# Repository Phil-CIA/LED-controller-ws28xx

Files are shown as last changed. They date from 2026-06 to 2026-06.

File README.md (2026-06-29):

# My LED Controller

Standalone ESP32 + WS281x project.

This repo now supports two firmware paths:
- custom firmware in `src/main.cpp` (serial-driven tests and demo)
- official WLED firmware (Wi-Fi + WLED app control)

This repo now also supports two hardware targets:
- `breadboard` target profile
- `pcb` target profile

Each target has independent identity lock (port/chip/MAC) in `scripts/flash-targets.json`.

## Hardware
- MCU: ESP32 family (default board config: esp32dev)
- LED data: GPIO18
- LED type: WS281x (NEO_GRB + 800kHz)
- LED count: 300
- Level shifter: 74H125
- Upload port: COM5

## Quick start
1. Set active target profile
   - Breadboard: `powershell -ExecutionPolicy Bypass -File scripts/set-active-target.ps1 -TargetName breadboard`
   - PCB: `powershell -ExecutionPolicy Bypass -File scripts/set-active-target.ps1 -TargetName pcb`
2. Build custom firmware for selected target
   - `powershell -ExecutionPolicy Bypass -File scripts/guarded-flash.ps1 -Action build`
3. Upload custom firmware for selected target (guarded)
   - `powershell -ExecutionPolicy Bypass -File scripts/guarded-flash.ps1 -Action upload`
4. Monitor
   - `platformio device monitor -b 115200 -p COM5`

## Target profile setup
Before first guarded flash on a target, pin its immutable MAC:
- `powershell -ExecutionPolicy Bypass -File scripts/set-target-mac.ps1 -TargetName pcb -ExpectedMac 11:22:33:44:55:66`

If `expectedMac` is empty for a target, guarded upload refuses to flash.

## WLED quick start (Wi-Fi + app)
1. Set active target profile first (`breadboard` or `pcb`).
2. Use the official installer at `https://install.wled.me` (ESP32 target).
3. Select the target COM port and complete flashing through the installer UI.
4. On first boot, connect to the WLED access point (`WLED-xxxxxx`) and open `http://4.3.2.1`.
5. In WLED settings, set hardware values to match this strip:
   - GPIO: `18`
   - LED count: `300`
   - Color order: `GRB`
6. Configure home Wi-Fi credentials in WLED settings and save.
7. Open the WLED app and add the device using `wled.local` or the assigned IP.
8. Set WLED max current to `12000 mA` for steady-state operation.
9. Discover by target profile:
   - Breadboard: `powershell -ExecutionPolicy Bypass -File scripts/discover-wled.ps1 -TargetName breadboard -OpenUi`
   - PCB: `powershell -ExecutionPolicy Bypass -File scripts/discover-wled.ps1 -TargetName pcb -OpenUi`

### If device reboots with `invalid header`
- This indicates an incompatible direct flash layout.
- Recover to known-good firmware with guarded upload:
  - `powershell -ExecutionPolicy Bypass -File scripts/guarded-flash.ps1 -Action upload`
- Then use `install.wled.me` instead of raw one-file `esptool write-flash` for WLED.

## Serial commands
- `on` => resume animation
- `off` => LEDs off
- `rainbow` => return to rainbow mode
- `white`, `red`, `green`, `blue` => solid color test
- `probe` => raw GPIO18 pulse test
- `b0` to `b255` => set brightness

## Rev B action list (from validated PCB bring-up)
- Keep LED outputs as validated:
   - external strip data on `GPIO18`
   - onboard 3-LED chain on `GPIO19`
- Keep sensor wiring as validated:
   - AHT20 `SDA=GPIO21`, `SCL=GPIO22`
   - I2C address detected at `0x38`
- Fix switch hardware biasing on PCB:
   - Current switch pins (`GPIO34`, `GPIO35`, `GPIO36`, `GPIO39`) have no internal pull-up/down support.
   - Add external pull resistors per switch (recommended: `10k` pull-up to `3.3V`, button to `GND`, active-low).
- Preserve guarded flash identity lock per target in `scripts/flash-targets.json`.
- Keep target-separated profiles (`breadboard`, `pcb`) and avoid MAC reuse across targets.

## PCB diagnostics commands
- `aht20` or `sensor` => read temperature/humidity from AHT20
- `i2cscan` or `scan` => scan bus and print detected I2C addresses
- `switches` or `inputs` => print raw switch pin states
- `boardcheck` or `diag` => run sensor + switches diagnostics together

## Notes
- If your exact ESP32 board is different, update `board` in platformio.ini.
- If colors are wrong, adjust pixel order in src/main.cpp.
- Keep strict target guardrails in place; do not flash unknown devices opportunistically.
- Use dedicated VS Code tasks per target (`Breadboard:*` and `PCB:*`).

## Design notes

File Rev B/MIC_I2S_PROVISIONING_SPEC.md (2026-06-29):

# Rev B Optional MIC_I2S Provisioning Spec

Date: 2026-06-29
Scope: Provision-only support for future WLED audio-reactive microphone input.

## Intent
- Add optional microphone connectivity in Rev B without requiring immediate microphone population.
- Keep primary LED controller behavior unchanged when microphone is not installed.
- Prefer I2S digital microphone compatibility for WLED.

## Locked Module and Connector
- Module lock: INMP441 I2S microphone module, 14 mm form factor.
- Implementation lock: custom device footprint already placed as U2.
- KiCad symbol/library: 1My_IC's:INMP441.
- KiCad footprint/library: 1My_Parts_ ICs:inmp441.
- Physical interface: dual 1x3 headers (2.54 mm), total 6 pins.

## Electrical Interface
Required nets for the optional interface:
- MIC_VDD
- MIC_GND
- MIC_I2S_BCLK
- MIC_I2S_WS
- MIC_I2S_SD
- MIC_LR_SEL

Current netlist implementation:
- U2 VDD is tied to +5V_CTRL.
- U2 L/R is tied to GND.

Optional protection/conditioning footprints (DNI by default):
- 3x series resistors (one per I2S signal, nominal 22R to 100R)
- 100 nF decoupling capacitor at MIC_3V3
- 10 uF local bulk capacitor at MIC_3V3

## Locked Pin Map (Classic ESP32)
Set A is now locked:
- GPIO32 -> MIC_I2S_BCLK
- GPIO33 -> MIC_I2S_WS
- GPIO35 -> MIC_I2S_SD
- MIC_LR_SEL -> GND (left-channel select for WLED compatibility)

## Locked Pin Functions (U2)
1. L/R -> MIC_LR_SEL (tied to GND)
2. WS -> MIC_I2S_WS
3. SCLK -> MIC_I2S_BCLK
4. SD -> MIC_I2S_SD
5. VDD -> MIC_VDD (currently +5V_CTRL)
6. GND -> MIC_GND

## KiCad Schematic Tasks
1. Keep U2 as the locked INMP441 device symbol and footprint pair.
2. Verify the U2 six pin functions match the locked mapping above.
3. Keep microphone path optional in documentation/BOM intent.
4. Keep design local to Rev B schematic only.

## KiCad PCB Tasks
1. Place/keep the U2 footprint in a low-noise region away from switching and high current LED paths.
2. Keep I2S traces short and direct; avoid crossing noisy return paths.
3. Add clear silkscreen orientation and signal labels.
4. Leave microphone and optional passives as DNI unless intentionally enabled.

## Verification
- ERC: no new unresolved errors caused by MIC_I2S nets.
- DRC: no new clearance/connectivity violations.
- Pin conflict check: selected I2S pins do not conflict with existing mapped functions.
- Pinout check: U2 pin-function mapping matches the locked U2 list.

## Future Bring-Up
When a microphone is populated:
1. Enable WLED AudioReactive.
2. Configure I2S mode.
3. Enter the final BCLK, WS, SD GPIO mapping.
4. Save config and perform a hardware reset.

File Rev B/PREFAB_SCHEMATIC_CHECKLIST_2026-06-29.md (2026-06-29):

# Rev B Schematic Pre-Fab Checklist

Date: 2026-06-29
Design: Rev B
Scope: Schematic-only pre-fab gate before PCB reroute.

## Baseline Inputs
- Schematic: [Rev B/My LED controller Rev B.kicad_sch](Rev B/My LED controller Rev B.kicad_sch)
- Netlist: [Rev B/My LED controller Rev B.net](Rev B/My LED controller Rev B.net)
- ERC report (new): [Rev B/ERC_PREFAB_2026-06-29.rpt](Rev B/ERC_PREFAB_2026-06-29.rpt)

## Gate Criteria
1. ERC errors: 0 required to pass.
2. ERC warnings: either resolved or explicitly accepted with rationale.
3. New microphone path fully documented and electrically intentional.
4. All power-net assumptions for microphone module confirmed.

## Current ERC Summary
- Total messages: 48
- Errors: 1
- Warnings: 47
- Source: [Rev B/ERC_PREFAB_2026-06-29.rpt](Rev B/ERC_PREFAB_2026-06-29.rpt)
- Latest synced run (after alias/severity tuning): 35 messages, 1 error, 34 warnings.
- Source: [Rev B/ERC_SYNC_NOW_2026-06-29.rpt](Rev B/ERC_SYNC_NOW_2026-06-29.rpt)

## Change Coverage Audit (2026-06-29)
Original mic-scope intent vs current schematic/netlist implementation.

Implemented:
- INMP441 symbol and footprint are present as U2.
- Set A I2S mapping is present:
  - GPIO32 -> MIC_I2S_BCLK
  - GPIO33 -> MIC_I2S_WS
  - GPIO35 -> MIC_I2S_SD
- L/R is tied to GND (left-channel select behavior).
- U2 VDD is tied to +5V_CTRL.

Open/mismatch items:
- GPIO33 still reports ERC pin_not_driven and is not closed yet.
- Net naming mismatch from earlier plan: MIC_VDD/MIC_GND/MIC_LR_SEL are not currently named nets in netlist.
- Earlier header-only checklist text in handoff is stale relative to current U2 module implementation.
- Explicit schematic note text for optional/DNI intent was not found in current schematic text export.

## Must Fix Before Pass
1. Input pin not driven on GPIO33 path
- Finding: U1 pin 7 (GPIO33) flagged as input not driven.
- Location in report: [Rev B/ERC_PREFAB_2026-06-29.rpt](Rev B/ERC_PREFAB_2026-06-29.rpt#L5)
- Likely cause: ESP32 symbol pin electrical type for GPIO33 is input while this net is used as I2S WS output.
- Planned action in schematic:
  - Option A: Override/adjust pin electrical type so WS source is considered driven.
  - Option B: Apply a targeted No ERC marker only if the connection is verified intentional.
- Status: Open

## Microphone-Specific Schematic Checks
1. INMP441 signal mapping
- MIC_I2S_BCLK -> U1 GPIO32 -> U2 SCLK
- MIC_I2S_WS -> U1 GPIO33 -> U2 WS
- MIC_I2S_SD -> U1 GPIO35 -> U2 SD
- L/R -> GND
- Status: Verify in schematic and netlist before closing.

2. Microphone supply net
- Current netlist shows U2 VDD on +5V_CTRL.
- Confirm module is 5V-safe for both supply and logic interaction with ESP32.
- If not 5V-safe, move to +3.3V and regenerate ERC/netlist.
- Status: Open decision

## Warnings Triage (Can Be Accepted With Rationale)
1. Missing external symbol/footprint libraries
- Multiple warnings indicate local library paths unavailable in current CLI environment.
- Action: Verify symbols and footprints resolve correctly on your KiCad workstation.
- Acceptable if resolved in your active KiCad setup.

2. Unspecified-to-passive / unspecified-to-power-input pin type warnings
- Mostly from imported symbols using generic or unspecified pin types.
- Action: Review only changed paths first (mic path and nearby affected nets).
- Acceptable if electrical intent is clear and no real connectivity fault exists.

3. Off-grid endpoint warnings
- Present around existing circuitry.
- Action: Snap relevant wire endpoints to grid where practical.
- Acceptable if connectivity is confirmed and no accidental opens.

## Schematic Sign-Off Checklist
- [ ] Fix or explicitly waive the single ERC error on GPIO33 path.
- [ ] Confirm microphone VDD net choice (+5V_CTRL vs +3.3V) against actual module capability.
- [ ] Confirm mic pin mapping against intended WLED configuration.
- [ ] Regenerate ERC and store report as a new revision file.
- [ ] Record final accepted warnings rationale in handoff note.

## Next Step After Schematic Pass
Proceed to PCB reroute, then run full-board final check (ERC + DRC + connectivity review).

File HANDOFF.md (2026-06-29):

# My LED Controller Handoff

## Current state
Standalone WS281x bring-up project for an ESP32 board on COM5.

Breadboard unit status:
- WLED is running and controllable over Wi-Fi.
- Breadboard is now considered a closed unit for this phase.

Repository status:
- Firmware workflow now supports separate target profiles (`breadboard`, `pcb`) with independent identity lock.
- Active target is controlled via `scripts/flash-targets.json` (`activeTarget`) or `-TargetName` on scripts.

WLED migration support has been added:
- guarded WLED flash script: `scripts/guarded-wled-flash.ps1`
- target-aware discovery script: `scripts/discover-wled.ps1`
- target management scripts:
  - `scripts/set-active-target.ps1`
  - `scripts/set-target-mac.ps1`
- VS Code tasks are now split per target (`Breadboard:*`, `PCB:*`)

WLED firmware has been flashed successfully:
- Binary: `WLED_16.0.0_ESP32.bin`
- Port: `COM5`
- Chip: `ESP32-D0WD-V3`
- Detected MAC: `14:33:5C:2F:27:C4`
- MAC pinning is now set in `scripts/flash-targets.json`

Important correction:
- Direct single-file `esptool` flash attempts with release `WLED_16.0.0_ESP32.bin` caused boot resets with `invalid header`.
- Known-good recovery path is `scripts/guarded-flash.ps1 -Action upload` (restores custom firmware and boot chain).
- Recommended WLED path for this board is the official installer: `https://install.wled.me` (ESP32 target), then run `scripts/discover-wled.ps1`.

## Known-good hardware assumptions
- Board: ESP32 family, current upload target is `esp32dev`
- Data pin: GPIO18
- LED count: 300
- Level shifter: 74H125
- Serial/upload port: COM5 (can differ per target profile later)

## Known-good software state
- PlatformIO environments:
  - `esp32_led_breadboard`
  - `esp32_led_pcb`
- Framework: Arduino
- Platform pinned to pioarduino stable release
- Guarded upload scripts check port + chip + pinned MAC for the selected target before flashing
- Firmware currently includes:
  - rainbow animation
  - flashy multi-phase demo routine (`demo`) for long-run strip testing
  - solid color modes
  - brightness command
  - current-limit command (`limit<ma>`) with hard cap at 15000 mA
  - raw GPIO18 `probe` command
  - startup RGBW diagnostic pulse sequence
  - steady-state default current limit of 12000 mA

## What was verified
- Build succeeded
- Guarded upload succeeded to COM5
- Chip on COM5 was confirmed as ESP32-D0WD-V3
- Hidden solder bridge on pins 1 and 2 had been the cause of the no-signal condition and was fixed
- The strip was observed working after that fix
- Current-limit behavior was verified over serial:
  - `limit15000` applies as expected
  - values above 15000 mA are clamped to 15000 mA
  - `limit12000` returns to the steady-state target
- Demo mode was flashed and started successfully (`demo` -> "Mode: demo")

## Files to open first
- `README.md`
- `platformio.ini`
- `src/main.cpp`
- `scripts/guarded-flash.ps1`

## Useful commands
- Set active target to breadboard: `powershell -ExecutionPolicy Bypass -File scripts/set-active-target.ps1 -TargetName breadboard`
- Set active target to PCB: `powershell -ExecutionPolicy Bypass -File scripts/set-active-target.ps1 -TargetName pcb`
- Pin PCB MAC before first guarded flash: `powershell -ExecutionPolicy Bypass -File scripts/set-target-mac.ps1 -TargetName pcb -ExpectedMac <MAC>`
- Build selected target: `powershell -ExecutionPolicy Bypass -File scripts/guarded-flash.ps1 -Action build`
- Upload selected target: `powershell -ExecutionPolicy Bypass -File scripts/guarded-flash.ps1 -Action upload`
- Flash WLED (recommended): use `https://install.wled.me` for the currently connected target
- Discover breadboard WLED: `powershell -ExecutionPolicy Bypass -File scripts/discover-wled.ps1 -TargetName breadboard -OpenUi`
- Discover PCB WLED: `powershell -ExecutionPolicy Bypass -File scripts/discover-wled.ps1 -TargetName pcb -OpenUi`
- Monitor: `C:/Users/user/.platformio/penv/Scripts/platformio.exe device monitor -b 115200 -p COM5`
- Start demo: send `demo` in serial monitor
- Return to steady current target: send `limit12000`
- Set temporary higher test limit: send `limit15000`
- Turn LEDs off: send `off`

## Notes for the next session
- Do not reuse breadboard MAC for PCB profile. Keep each target identity pinned separately.
- For PCB bring-up, set PCB target MAC first; guarded flash intentionally fails if `expectedMac` is empty.
- Keep this project isolated from the older WorkStation repo unless you intentionally need to cross-reference it.
- If the LEDs stop responding again, first check for hardware shorts, power, and ground before changing firmware.
- If you want to simplify the firmware later, the startup probe sequence can be removed after bring-up is complete.
- Current policy: run steady around 12 A, allow up to 15 A max during testing/effect changes.
- If upload fails with COM5 busy/access denied, close any active serial monitor terminal first.
- After flashing WLED, set LED config in WLED UI to GPIO18, 300 LEDs, GRB, and set max current to 12000 mA.

## Session closeout (2026-06-29)

This session finalized repository synchronization and Rev B tracking publication.

### What was completed
- Created and linked the living Rev B planning artifacts:
  - `REV_B_CHANGE_TRACKER.md`
  - `NEXT_CHAT_QUICKSTART.md`
- Reconciled local workspace content with GitHub `main` using additive merge-style commits.
- Published firmware/docs/scripts that existed locally but were not yet tracked on GitHub.
- Cleaned workspace clutter and updated ignore rules for generated files.

### Latest GitHub state
- Remote: `https://github.com/Phil-CIA/LED-controller-ws28xx`
- Branch: `main`
- Current head at closeout: `7832305`
- Recent relevant commits:
  - `7832305` Merge local firmware workspace into repo (scripts, src, docs)
  - `d608d14` Add living Rev B change tracker and link quickstart

### Files now available on GitHub for laptop sync
- `HANDOFF.md`
- `README.md`
- `platformio.ini`
- `src/main.cpp`
- `scripts/discover-wled.ps1`
- `scripts/flash-targets.json`
- `scripts/guarded-flash.ps1`
- `scripts/guarded-wled-flash.ps1`
- `scripts/set-active-target.ps1`
- `scripts/set-target-mac.ps1`
- `REV_B_CHANGE_TRACKER.md`
- `NEXT_CHAT_QUICKSTART.md`

### Laptop sync steps
1. Open terminal in the laptop clone of this repo.
2. Run `git checkout main`.
3. Run `git pull origin main`.
4. Verify with `git log --oneline -n 3` and confirm commit `7832305` is present.

### Ongoing process
- Keep `REV_B_CHANGE_TRACKER.md` as the authoritative living change register for Rev B.
- Update `HANDOFF.md` at each session close with what changed, what was validated, and the latest commit reference.

## Session closeout (2026-06-29, Rev B pre-route handoff)

This closeout completes repository sync and publishes the Rev B baseline artifacts needed before board routing.

### What was completed
- Created a safety snapshot branch before sync: `wip/pre-sync-2026-06-29` at `80bd3fa`.
- Fast-forward synced local `main` to remote `origin/main`.
- Imported Rev B design and pre-fab artifacts into `main` and pushed to GitHub.
- Added merged direction plan for pre-route execution in `REV_B_MERGED_DIRECTION_2026-06-29.md`.

### Latest GitHub state
- Branch: `main`
- Current head at closeout: `0191824`
- Closeout commit: `0191824` Add Rev B design baseline and prefab mic closeout artifacts

### Rev B pre-route gate (must finish before routing)
1. Resolve or explicitly waive the GPIO33 ERC input-not-driven finding.
2. Lock microphone VDD decision (+5V_CTRL only if confirmed safe; else move to +3.3V).
3. Reconcile mic net naming/docs mismatch and ensure optional or DNI intent is explicit.
4. Re-run Rev B ERC and DRC with reports saved as new revision artifacts.

### Start-next-session focus
- Execute the pre-route gate items above first.
- After gate pass, begin RB-001 and RB-007 implementation before broader reroute work.

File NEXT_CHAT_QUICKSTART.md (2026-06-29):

# Next Chat Quick Start - Rev B Pre-Route Execution

Primary tracker document: `REV_B_CHANGE_TRACKER.md` (living document, continuously updated)

## Goal for next chat
Complete the Rev B schematic pre-route gate, then start the first must-have board changes.

## Paste this at the start of the next chat
Use this workspace to execute Rev B pre-route gates first, then begin layout must-haves.

Known validated state:
- PCB target identity locked and guarded upload working on COM6
- External strip path validated on GPIO18
- Onboard 3-LED path validated on GPIO19
- AHT20 validated on I2C: SDA GPIO21, SCL GPIO22, device at address 0x38
- Switches currently unreliable due to hardware biasing limits on GPIO34/35/36/39

Pre-route findings already identified:
- Rev B mic path is implemented as U2 INMP441 with Set A GPIO mapping.
- One true ERC blocker remains on GPIO33 (input-not-driven).
- Mic VDD decision is still open (+5V_CTRL vs +3.3V).
- Mic naming/docs mismatch is still open.

Please execute in this order:
1. Close the GPIO33 ERC blocker (fix or explicit waiver with rationale).
2. Lock mic VDD rail decision and apply schematic update if needed.
3. Resolve mic naming/docs mismatch and ensure optional or DNI intent is explicit.
4. Regenerate Rev B ERC and DRC artifacts.
5. If gate passes, start RB-001 and RB-007 before broader reroute.

Then update:
- REV_B_CHANGE_TRACKER status fields for completed pre-route items.
- HANDOFF with exact decisions and artifact filenames.

## Current source of truth
- HANDOFF: HANDOFF.md
- Pre-route execution plan: REV_B_MERGED_DIRECTION_2026-06-29.md
- Rev B prefab checklist: Rev B/PREFAB_SCHEMATIC_CHECKLIST_2026-06-29.md
- Main firmware: src/main.cpp
- Build config and pins: platformio.ini
- Guarded flash flow: scripts/guarded-flash.ps1
- Target identity config: scripts/flash-targets.json

## First implementation block (after pre-route gate)
### Hardware and layout must-haves
- RB-001: add external pull-up network for switch lines GPIO34/35/36/39.
- RB-007: correct onboard LED serial chain first-LED orientation (DIN path).
- RB-002: route and place switch pull network near MCU pins.
- RB-003/RB-005: onboard LED section and R16 relocation work.

## Fast command reference
- KiCad ERC (Rev B schematic):
  C:/Users/forch/AppData/Local/Programs/KiCad/9.0/bin/kicad-cli.exe sch erc "c:/Users/forch/GitHub/LED-controller-ws28xx/Rev B/My LED controller Rev B.kicad_sch" --output "c:/Users/forch/GitHub/LED-controller-ws28xx/Rev B/ERC_NEXT_SESSION_YYYY-MM-DD.rpt"

- KiCad DRC (Rev B PCB):
  C:/Users/forch/AppData/Local/Programs/KiCad/9.0/bin/kicad-cli.exe pcb drc "c:/Users/forch/GitHub/LED-controller-ws28xx/Rev B/My LED controller Rev B.kicad_pcb" --output "c:/Users/forch/GitHub/LED-controller-ws28xx/Rev B/DRC_NEXT_SESSION_YYYY-MM-DD.rpt"

- Build PCB firmware:
  powershell -ExecutionPolicy Bypass -File scripts/guarded-flash.ps1 -Action build -TargetName pcb

- Upload PCB firmware (guarded):
  powershell -ExecutionPolicy Bypass -File scripts/guarded-flash.ps1 -Action upload -TargetName pcb

- Serial monitor:
  C:/Users/user/.platformio/penv/Scripts/platformio.exe device monitor -b 115200 -p COM6

- Diagnostics in serial:
  i2cscan
  aht20
  switches
  boardcheck

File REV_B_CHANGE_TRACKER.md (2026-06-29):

# Rev B Change Tracker (Living Document)

## Intent
This is the working change-control document for the next PCB revision.

Scope:
- Hardware schematic changes
- PCB layout changes
- Firmware changes
- Manufacturing and assembly changes
- Test and validation changes
- Documentation updates

Policy:
- This document is intentionally changeable at any time.
- New items can be added, edited, re-prioritized, or deferred as findings evolve.
- Nothing is considered locked until the Rev B freeze decision is recorded in the Decision Log.

## Baseline Constraints To Preserve
- Keep strict guarded flash identity checks (port, chip, MAC).
- Preserve known-good behavior unless a change is explicitly approved.
- Avoid COM port shopping and stop on target mismatch.

## Current Known-Good Validation Baseline
- External strip path validated on GPIO18.
- Onboard 3-LED path validated on GPIO19.
- AHT20 validated on I2C SDA GPIO21 and SCL GPIO22 at address 0x38.
- Guarded upload working for PCB target on COM6.

## Active Issue and Change Register

Status values: Open, In Progress, Blocked, Done, Deferred.

| ID | Category | Change Request | Priority | Status | Dependency | Validation Gate | Risk If Deferred |
|---|---|---|---|---|---|---|---|
| RB-001 | Hardware schematic | Add external pull-up network for switch lines GPIO34/35/36/39 (active-low switches) | Must | Open | None | `switches` command stable and repeatable | Unreliable switch input behavior |
| RB-002 | PCB layout | Route and place switch pull network near MCU pins | Must | Open | RB-001 | Switch line noise and false-trigger checks pass | Continued switch instability |
| RB-003 | PCB layout | Relocate onboard status LED section | Must | Open | RB-007 | Onboard LEDs pass startup and command tests | Congested routing and placement conflicts |
| RB-004 | PCB layout | Relocate AHT20 circuit to free spare header strip placement area | Must | Open | Schematic net keep or approved remap | `i2cscan` finds 0x38, `aht20` plausible readings | Header placement blocked or sensor regression |
| RB-005 | Hardware + layout | Relocate R16 (series resistor on onboard LED data path) near source GPIO path | Must | Open | RB-003 | Onboard data signal integrity verified | Data edge quality and debugging difficulty |
| RB-006 | PCB layout | Move main terminal block for silkscreen readability | Must | Open | None | Labels readable and polarity unmistakable | Wiring/setup errors in assembly and field |
| RB-007 | Hardware + layout | Correct onboard LED serial chain first-LED orientation (DIN path) | Must | Open | None | Onboard chain responds correctly in order | Onboard LED chain malfunction |
| RB-008 | Hardware decision | Dedicated level shift for onboard LEDs | Nice | Open | RB-003 routing review | SI review outcome documented | Possible margin loss in noisy scenarios |
| RB-009 | WLED optimization | Add clear silkscreen labels for WLED setup points (GPIO18 data, GND, 5V, current target note) | Must | Open | RB-006 | Setup can be completed from silkscreen + docs | Higher setup error rate |
| RB-010 | Documentation | Add concise WLED setup instructions to docs and board labels | Must | Open | RB-009 | New user can configure WLED without guesswork | Slower bring-up and support overhead |
| RB-011 | Pre-route schematic gate | Resolve or explicitly waive GPIO33 ERC input-not-driven finding on Rev B mic path | Must | Open | None | Rev B ERC shows 0 errors or documented waiver accepted | Routing starts with unresolved electrical intent |
| RB-012 | Pre-route hardware decision | Lock Rev B microphone VDD rail decision (+5V_CTRL or +3.3V) and apply schematic update if required | Must | Open | RB-011 | Schematic and netlist match chosen rail and rationale recorded | Risk of mic supply incompatibility or rework |
| RB-013 | Pre-route documentation consistency | Reconcile mic net naming and optional or DNI documentation with implemented U2 module wiring | Must | Open | RB-012 | Handoff, checklist, and schematic notes match implementation | Build ambiguity and bring-up confusion |

## WLED-First Board Guidance (Working)
- Keep external strip data path aligned with current known-good GPIO18 unless routing forces change.
- Keep onboard LED path simple by default (no dedicated level shifter unless SI evidence requires it).
- Keep WLED setup discoverable from silkscreen and docs.

## Verification Checklist (Per Build Candidate)
- Guarded upload precheck passes for PCB target.
- `i2cscan` detects 0x38.
- `aht20` returns plausible temperature/humidity.
- `switches` reports stable button states.
- External strip and onboard LEDs both pass functional tests.
- WLED setup succeeds using documented/silkscreened instructions.

## Decision Log
Use this section to record decisions that freeze scope.

| Date | ID | Decision | Rationale | Approved By |
|---|---|---|---|---|
| 2026-06-24 | RB-008 | Do not add dedicated onboard LED level shifter by default | Keep complexity and BOM lower unless routing/SI review shows need | Working decision |

## Change Log
| Date | Summary |
|---|---|
| 2026-06-24 | Initialized living Rev B tracker with known baseline and newly requested changes. |
| 2026-06-29 | Added explicit pre-route gate items RB-011 through RB-013 for Rev B mic/ERC closeout before routing. |

## Update Rules
When adding or changing an item:
1. Add or update the ID in Active Issue and Change Register.
2. Set Priority and Status.
3. Add clear Validation Gate text.
4. If scope is frozen, record in Decision Log.
5. Add one line to Change Log.

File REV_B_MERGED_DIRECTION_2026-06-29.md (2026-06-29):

# Rev B Merged Direction (2026-06-29)

Purpose: unify the upstream Rev B change tracker direction with local Rev B microphone and schematic closeout work.

## Source Inputs
- REV_B_CHANGE_TRACKER.md
- NEXT_CHAT_QUICKSTART.md
- Rev B/PREFAB_SCHEMATIC_CHECKLIST_2026-06-29.md (from WIP snapshot branch)
- Rev B/REV_B_HANDOFF.md (from WIP snapshot branch)

## What Is Now Synced
- Local main is fast-forwarded to origin/main at commit 529a03d.
- Local pre-sync work is preserved in branch wip/pre-sync-2026-06-29 at commit 80bd3fa.

## Integrated Work Plan (Single Direction)

### Phase 1: Schematic close gate (must complete before reroute)
1. Close the one real ERC blocker on GPIO33 (input-not-driven) using one of:
   - pin-type correction, or
   - targeted No ERC waiver with rationale.
2. Finalize microphone VDD decision:
   - keep +5V_CTRL only if module compatibility is confirmed, else move to 3.3V.
3. Reconcile mic naming/documentation mismatch:
   - either add MIC_VDD/MIC_GND/MIC_LR_SEL style nets, or
   - update docs to match actual implemented net naming.
4. Ensure optional or DNI intent is visible in schematic notes.
5. Regenerate Rev B ERC and mark schematic gate pass only when errors are zero or explicitly waived.

### Phase 2: PCB reroute and Rev B layout must-haves
Execute the current must items from the tracker in dependency order:
1. RB-001 switch pull-up network in schematic.
2. RB-002 switch pull network routing near MCU pins.
3. RB-007 onboard LED serial chain first-LED orientation correction.
4. RB-003 onboard status LED section relocation.
5. RB-005 R16 relocation near source GPIO path.
6. RB-004 AHT20 relocation while preserving validated I2C behavior.
7. RB-006 main terminal block move for silkscreen readability.
8. RB-009 WLED setup silkscreen labels.
9. RB-010 documentation updates aligned with new silkscreen/setup flow.

### Phase 3: Firmware and validation lock
1. Keep guarded flash identity checks unchanged.
2. Run verification sequence per board candidate:
   - guarded upload precheck pass,
   - i2cscan returns 0x38,
   - aht20 plausible values,
   - switches stable and repeatable,
   - onboard and external LED function pass,
   - WLED setup succeeds from labels and docs.
3. Keep RB-008 as a conditional decision unless routing or SI evidence requires change.

## Immediate Next Session Task List
1. Bring Rev B files from wip/pre-sync-2026-06-29 into tracked main workstream.
2. Fix GPIO33 ERC status and lock mic VDD decision.
3. Re-run Rev B ERC and DRC after schematic updates.
4. Update REV_B_CHANGE_TRACKER.md status fields for completed schematic gates.
5. Start reroute with RB-001 and RB-007 first (highest functional risk).

## Notes
- Current tracker in main governs prioritization and status.
- WIP Rev B mic files remain the detailed implementation reference until merged onto main.

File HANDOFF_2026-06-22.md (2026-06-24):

# LED Controller WS28xx — Handoff: Board Connection & Validation Phase

**Date:** 2026-06-22  
**Phase:** PMOS Reverse-Polarity Protection Diagnosis → Fix Validation  
**Status:** Schematic modifications complete; ready for bench test  

---

## Phase Completed: Reverse-Polarity Protection Debugging

### Problem Statement
Q1 (BSP322PH6327 P-channel MOSFET SOT-223) in the reverse-polarity protection stage was not conducting properly:
- Measured **VIN_REVPROT = 4.62V** at 5V input (should be ~5V for full conduction)
- Indicated insufficient gate-source bias voltage to enhance the PMOS channel
- Board was relying on expensive body-diode conduction rather than efficient MOSFET channel

### Root Cause Identified
Gate bias network (R5/R6 divider to ground) was producing insufficient negative gate voltage:
- **Original:** R5 = 10kΩ (to VIN_RAW), R6 = 100kΩ (to GND)  
- This gave $V_G = \frac{5V \times 10k}{10k + 100k} = 0.45V$
- Therefore $V_{GS} = 0.45V - 5V = -0.45V$ (too shallow for PMOS enhancement)

### Solution Implemented: R5/R6 Swap
**Resistor values swapped to increase pull-down strength:**

| Component | Before | After | Purpose |
|---|---|---|---|
| **R5** | 10kΩ (PCM_JLCPCB C17414) | **100kΩ** (PCM_JLCPCB C149504) | Weaker pull to VIN_RAW |
| **R6** | 100kΩ (PCM_JLCPCB C149504) | **10kΩ** (PCM_JLCPCB C17414) | Stronger pull to GND |

**New divider calculation at 5V input:**
$$V_G = \frac{5V \times 10k}{100k + 10k} = 0.45V$$
$$V_{GS} = 0.45V - 5V = -4.55V$$

This provides **~4.55V of gate-source enhancement voltage**, strongly pulling current through the MOSFET channel instead of relying on body diode.

---

## Files Modified & Committed

### 1. **My LED controller.kicad_sch** (Primary Source)
- R5 symbol: Updated to 100kΩ, lib_id changed to "PCM_JLCPCB-Resistors:0805,100kΩ"
- R6 symbol: Updated to 10kΩ, lib_id changed to "PCM_JLCPCB-Resistors_1:0805,10kΩ"  
- LCSC part numbers swapped between R5/R6
- Datasheets updated for both resistors

### 2. **My LED controller.net** (Regenerated Netlist)
- Regenerated from schematic using `kicad-cli sch export netlist`
- Contains updated BOM metadata for R5 and R6

### 3. **My LED controller.kicad_pcb** (PCB Metadata)
- Footprint properties updated for R5 and R6
- All component references synchronized

### 4. **.gitignore** (New)
- Added rules to exclude KiCad temporary files:
  - `#auto_saved_files#/`, `_autosave-*.kicad_*`, `~*.lck`, `*.rpt`, `*.csv`, `bom/`, `fp-info-cache`

### 5. **Commit Hash:** `dd87ed8`
```
Swap Q1 gate bias resistors: R5 100k (to VIN_RAW), R6 10k (to GND) 
for better PMOS turn-on at 5V input
```

---

## Next Phase: Board Connection & Measurement Validation

### Objective
Verify that the resistor swap produces the expected gate-source voltage and increases VIN_REVPROT from 4.62V toward 5V.

### Hardware Setup Required
1. **Connect power to VIN_RAW (5V nominal)**
2. **Measure at Q1 gate (net: Q1_GATE)**
   - Expected: ~0.45V (divider output)
3. **Measure VIN_REVPROT (after Q1 drain)**
   - Current state: 4.62V ❌
   - Expected after fix: ~4.9–5.0V ✅
4. **Optional: Measure Vgs directly across Q1**
   - Expected: ~-4.55V (gate at 0.45V, source at 5V)

### Interpretation of Results

#### Success Scenario
If **VIN_REVPROT measures ≥4.9V** at 5V input:
- Gate bias fix worked correctly
- PMOS is now conducting in enhancement mode with good channel resistance
- Proceed to full board testing (load testing, reverse-polarity test)

#### Partial Success (VIN_REVPROT = 4.62–4.8V)
- Indicates gate bias improved but PMOS still not fully enhanced
- Check for:
  - PCB layout issues (high trace resistance on Q1 gate pull-down)
  - Component soldering quality or part substitution
  - Gate-to-source leakage path

#### Failure (VIN_REVPROT still ≈4.62V or lower)
- Gate bias swap alone did not resolve the issue
- **Likely secondary cause:** D/S pins swapped on Q1 package or symbol
  - BSP322PH6327 footprint may have drain/source reversed
  - Requires symbol/footprint rework and PCB trace remapping
  - Contact board design reference to verify pin assignments

---

## Testing Checklist

- [ ] Power supply connected to VIN_RAW (5V, current-limited initially)
- [ ] Multimeter in voltage measurement mode
- [ ] Gate voltage (Q1_GATE) confirmed ~0.45V
- [ ] VIN_REVPROT measured at Q1 drain
- [ ] Vgs voltage verified (0.45V − 5V = −4.55V expected)
- [ ] Results documented with photos/notes
- [ ] If successful: proceed to load test on +5V_CTRL rail

---

## Known Limitations & Open Issues

1. **PCB physical modification not performed**  
   - Current board still has old R5/R6 values physically installed
   - Must physically swap resistors (0805 package) before testing
   - See component placements on PCB for R5/R6 locations

2. **Possible secondary issue (D/S swap)**  
   - If gate bias fix alone does not resolve VIN_REVPROT, investigate Q1 pin mapping
   - May require symbol library update and board rework

3. **Lock files cleaned**  
   - `.gitignore` now excludes temporary KiCad files
   - Previous backups in `My LED controller-backups/` remain for reference

---

## Contact / Notes
- Schematic changes validated via git diff
- Repository pushed to GitHub: https://github.com/Phil-CIA/LED-controller-ws28xx
- Netlist regenerated and committed
- All KiCad temporary files cleaned from working tree

**Next action:** Connect board, swap physical R5/R6 resistors, and measure VIN_REVPROT at 5V input.

## Bench Validation Update (2026-06-24)

Bench validation remains pending physical hardware access. Use this table to capture measured values when the board is on the bench:

| Measurement | Target | Measured | Status |
|---|---:|---:|---|
| VIN_RAW | 5.00V nominal | TBD | Pending |
| Q1_GATE (Net-(Q1-G)) | ~0.45V | TBD | Pending |
| VIN_REVPROT | 4.9V to 5.0V | TBD | Pending |
| VGS(Q1) | ~-4.55V | TBD | Pending |

Notes:
- R5/R6 value swap is present in schematic/netlist/PCB metadata from commit `dd87ed8`.
- Physical resistor swap and multimeter capture are still required to close #1.

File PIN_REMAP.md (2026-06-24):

# ESP32 Classic Pin Remap for WLED (LED-controller-ws28xx)

## WLED Data Channel Mapping (current schematic nets)

| WLED Channel | ESP32 GPIO | 74AHCT125 Path | Board Net | Board Connector Target |
|---|---:|---|---|---|
| Main Strip Data | GPIO18 | U4 2A -> 2Y | `LED_STRIP` | `U9` LED_STRIP_CONN pin 2 (data) |
| Spare Output 1 | GPIO16 | U4 3A -> 3Y | `3Y` | `J4` SPARE_OUT_HDR pin 1 |
| Spare Output 2 | GPIO17 | U4 4A -> 4Y | `4Y` | `J4` SPARE_OUT_HDR pin 2 |
| Status LED Driver | GPIO19 | U4 1A -> 1Y | `STATUS_LED` | Status LED path (`R16`/`D1`) |

## New Spare Header (SMT)

| Header | Pin | Net | Purpose |
|---|---:|---|---|
| `J4` SPARE_OUT_HDR | 1 | `3Y` | Spare buffered data output #1 |
| `J4` SPARE_OUT_HDR | 2 | `4Y` | Spare buffered data output #2 |
| `J4` SPARE_OUT_HDR | 3 | `GND` | Signal reference |
| `J4` SPARE_OUT_HDR | 4 | `+5V_CTRL` | Optional pull-up/peripheral power |

## ESP32 Classic GPIO Capability Flags

### Input-only GPIOs (do not use for LED data outputs)
`GPIO34`, `GPIO35`, `GPIO36`, `GPIO39`

### Flash-reserved GPIOs (do not use)
`GPIO6`–`GPIO11`

### Boot-strapping sensitive GPIOs (usable with caution)
`GPIO0`, `GPIO2`, `GPIO15`

### Actively used in this design
`GPIO12`, `GPIO13`, `GPIO14`, `GPIO16`, `GPIO17`, `GPIO18`, `GPIO19`, `GPIO23`, `GPIO34`, `GPIO35`, `GPIO36`, `GPIO39`

## WLED Recommendation
Use `GPIO18` as the primary strip output (`LED_STRIP`). Keep `GPIO16` and `GPIO17` as optional secondary WLED outputs via `J4` when multi-channel outputs are needed. Avoid assigning WLED data outputs to GPIO34/35/36/39 because they are input-only on classic ESP32.

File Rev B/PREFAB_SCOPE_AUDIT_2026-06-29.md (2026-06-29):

# Rev B Pre-Fab Scope Audit (Broadened)

Date: 2026-06-29

## Why this audit
The scope was broadened from mic-only checks to full repo-level pre-fab context, including library environment consistency and DRC/ERC interpretation.

## Evidence reviewed
- Root ERC baseline: [ERC_ROOT_BASELINE_2026-06-29.rpt](../ERC_ROOT_BASELINE_2026-06-29.rpt)
- Rev B ERC baseline: [ERC_PREFAB_2026-06-29.rpt](ERC_PREFAB_2026-06-29.rpt)
- Rev B ERC after local lib-table sync: [ERC_PREFAB_2026-06-29_LIBTABLE_SYNC.rpt](ERC_PREFAB_2026-06-29_LIBTABLE_SYNC.rpt)
- Rev B DRC baseline: [DRC_PREFAB_2026-06-29.rpt](DRC_PREFAB_2026-06-29.rpt)
- Rev B netlist: [My LED controller Rev B.net](My%20LED%20controller%20Rev%20B.net)

## Key conclusion
Library warnings are not primarily caused by copying to Rev B. Similar library-name issues exist at root level. Rev B copy did not introduce the class of warnings; it exposed existing library-name/environment dependencies.

## Issue classes and status

1. Electrical pre-route blockers (must close)
- Rev B ERC still has one real error: GPIO33 pin_not_driven on MIC_I2S_WS path.
- Status: Open.

2. Microphone power assumption (must decide)
- Netlist currently shows U2 VDD tied to +5V_CTRL.
- This is acceptable only if the selected 14 mm module is explicitly 5V-safe.
- Status: Open decision.

3. Library-name mismatches (environment/tooling)
- Missing symbol-library names in ERC include: Espressif, easyeda2kicad, 1My Basic Componets, 1My Passive.
- Missing footprint-library names in ERC include: PCM_Espressif, PCM_4ms_Package_SSOP.
- Status: Open, non-routing-critical if local overrides are accepted and symbol/footprint resolution works in your KiCad UI.

4. DRC unconnected items (routing stage artifacts)
- Rev B DRC reports 121 unconnected items and 17 violations.
- Large unconnected count is expected pre-reroute and not a library-copy symptom.
- Status: Expected at this stage; to be re-evaluated after reroute.

## Actions completed in this pass
- Copied global KiCad tables into Rev B project folder:
  - [sym-lib-table](sym-lib-table)
  - [fp-lib-table](fp-lib-table)
- Re-ran ERC after sync. Result stayed materially the same, confirming warnings are primarily library-name mapping/alias issues, not absence of table files alone.

## Recommended closeout order
1. Clear/waive GPIO33 pin_not_driven intentionally.
2. Confirm INMP441 module supply requirement and lock VDD net (+5V_CTRL or +3.3V).
3. Perform PCB reroute.
4. Re-run ERC + DRC and then triage remaining library-name warnings separately from electrical/layout errors.

## Notes on library portability
Current library resolution depends on absolute OneDrive/AppData paths. For portable repo builds, migrate required custom symbols/footprints into a repo-scoped library set and update project tables to relative paths.

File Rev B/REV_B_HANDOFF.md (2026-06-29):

# Rev B Handoff Note

Date: 2026-06-26
Repo: LED-controller-ws28xx

## Purpose
This folder snapshots the current KiCad design state as a Rev B working baseline for upcoming schematic/PCB changes.

## Source Snapshot
Files were copied from the repository root and renamed with "Rev B":
- My LED controller.kicad_sch -> My LED controller Rev B.kicad_sch
- My LED controller.kicad_pcb -> My LED controller Rev B.kicad_pcb
- My LED controller.kicad_pro -> My LED controller Rev B.kicad_pro
- My LED controller.kicad_prl -> My LED controller Rev B.kicad_prl

## Current Focus
Primary validation objective carried from prior handoff:
- Verify PMOS reverse-polarity gate-bias fix (R5/R6 swap) on hardware.
- Confirm VIN_REVPROT rises toward 4.9-5.0V at 5V input.

## Next Steps
1. Open the Rev B project files in KiCad for all new edits.
2. Keep Rev B changes isolated from root-level files.
3. Record bench measurements and update handoff notes after validation.

## Microphone Provisioning Implementation (Rev B)

Objective: add optional microphone support for WLED without populating a microphone by default.

### Provisioning Scope
- Interface: I2S digital microphone path (primary WLED-compatible option).
- Build intent: header-only provisioning, no mandatory mic population.
- Power intent: expose 3V3 and GND at mic header.
- Feature intent: keep this optional and non-blocking for primary LED controller operation.

### Provisional Net Plan
- MIC_3V3
- MIC_GND
- MIC_I2S_BCLK
- MIC_I2S_WS
- MIC_I2S_SD

### Locked GPIO Reservation
- Set A locked: GPIO32 (BCLK), GPIO33 (WS), GPIO35 (SD, input).

### Locked Module and Board Interface
- Module lock: INMP441 I2S microphone module, 14 mm, dual 1x3 headers.
- Current implementation reference: U2.
- KiCad symbol/library: 1My_IC's:INMP441.
- KiCad footprint/library: 1My_Parts_ ICs:inmp441.
- Locked U2 pin mapping:
	1) L/R -> GND (left-channel select)
	2) WS -> MIC_I2S_WS
	3) SCLK -> MIC_I2S_BCLK
	4) SD -> MIC_I2S_SD
	5) VDD -> +5V_CTRL
	6) GND -> GND

Notes:
- Keep SD on an input-capable pin for clean I2S receive mapping.
- Keep the entire microphone path optional and DNI by default.

### KiCad Edit Checklist
1. In the Rev B schematic, add an unpopulated microphone header symbol labeled MIC_I2S.
2. Label pins with the provisional net plan above.
3. Add schematic note: "Optional feature, DNI by default".
4. In the Rev B PCB, place the MIC_I2S footprint in a low-noise area away from high-current switching paths.
5. Route or prepare short, clean breakout routing for MIC_I2S signals with clear silkscreen pin naming.
6. Run ERC/DRC and capture any new warnings before closing the change.

### Firmware Bring-Up Note (Future)
- WLED AudioReactive should be configured for I2S mic mode once hardware is populated.
- Record final GPIO assignment in handoff and pin map after schematic/PCB lock.

### Implementation Reference
- See `Rev B/MIC_I2S_PROVISIONING_SPEC.md` for the current Rev B microphone provisioning baseline.

## Pre-Fab Schematic Check (Started 2026-06-29)
- Checklist: `Rev B/PREFAB_SCHEMATIC_CHECKLIST_2026-06-29.md`
- ERC baseline report: `Rev B/ERC_PREFAB_2026-06-29.rpt`
- Current blocker to clear before schematic pass: GPIO33 path flagged as input-not-driven in ERC.

## Broadened Scope Audit (2026-06-29)
- Audit summary: `Rev B/PREFAB_SCOPE_AUDIT_2026-06-29.md`
- Root ERC comparison report: `ERC_ROOT_BASELINE_2026-06-29.rpt`
- Rev B DRC baseline: `Rev B/DRC_PREFAB_2026-06-29.rpt`
- Rev B local lib-table sync artifacts: `Rev B/sym-lib-table`, `Rev B/fp-lib-table`
- Rev B ERC after lib-table sync: `Rev B/ERC_PREFAB_2026-06-29_LIBTABLE_SYNC.rpt`

## Library Alias Pass (2026-06-29)
- Added Rev B project-local library aliases in `Rev B/sym-lib-table` and `Rev B/fp-lib-table`.
- Tuned Rev B-only library-related severities in `Rev B/My LED controller Rev B.kicad_pro` from warning to ignore for pre-route checks.
- ERC progression:
	- Baseline: `Rev B/ERC_PREFAB_2026-06-29.rpt` (48 messages)
	- Alias pass: `Rev B/ERC_PREFAB_2026-06-29_ALIAS_PASS.rpt` (44 messages)
	- Alias + severity pass: `Rev B/ERC_PREFAB_2026-06-29_ALIAS_PASS2.rpt` (35 messages)
- DRC progression:
	- Baseline: `Rev B/DRC_PREFAB_2026-06-29.rpt` (17 violations)
	- Alias + severity pass: `Rev B/DRC_PREFAB_2026-06-29_ALIAS_PASS2.rpt` (13 violations)

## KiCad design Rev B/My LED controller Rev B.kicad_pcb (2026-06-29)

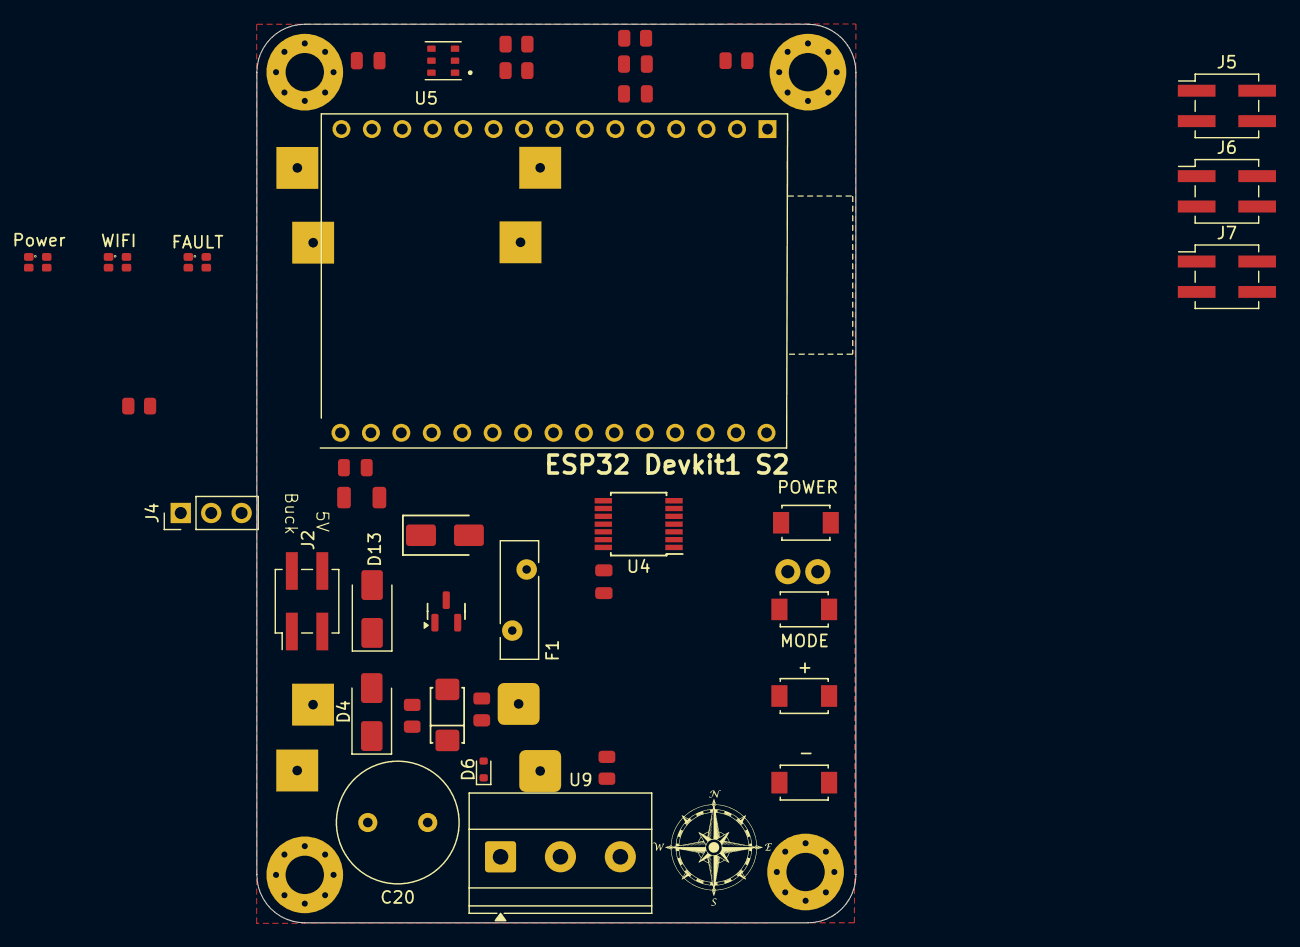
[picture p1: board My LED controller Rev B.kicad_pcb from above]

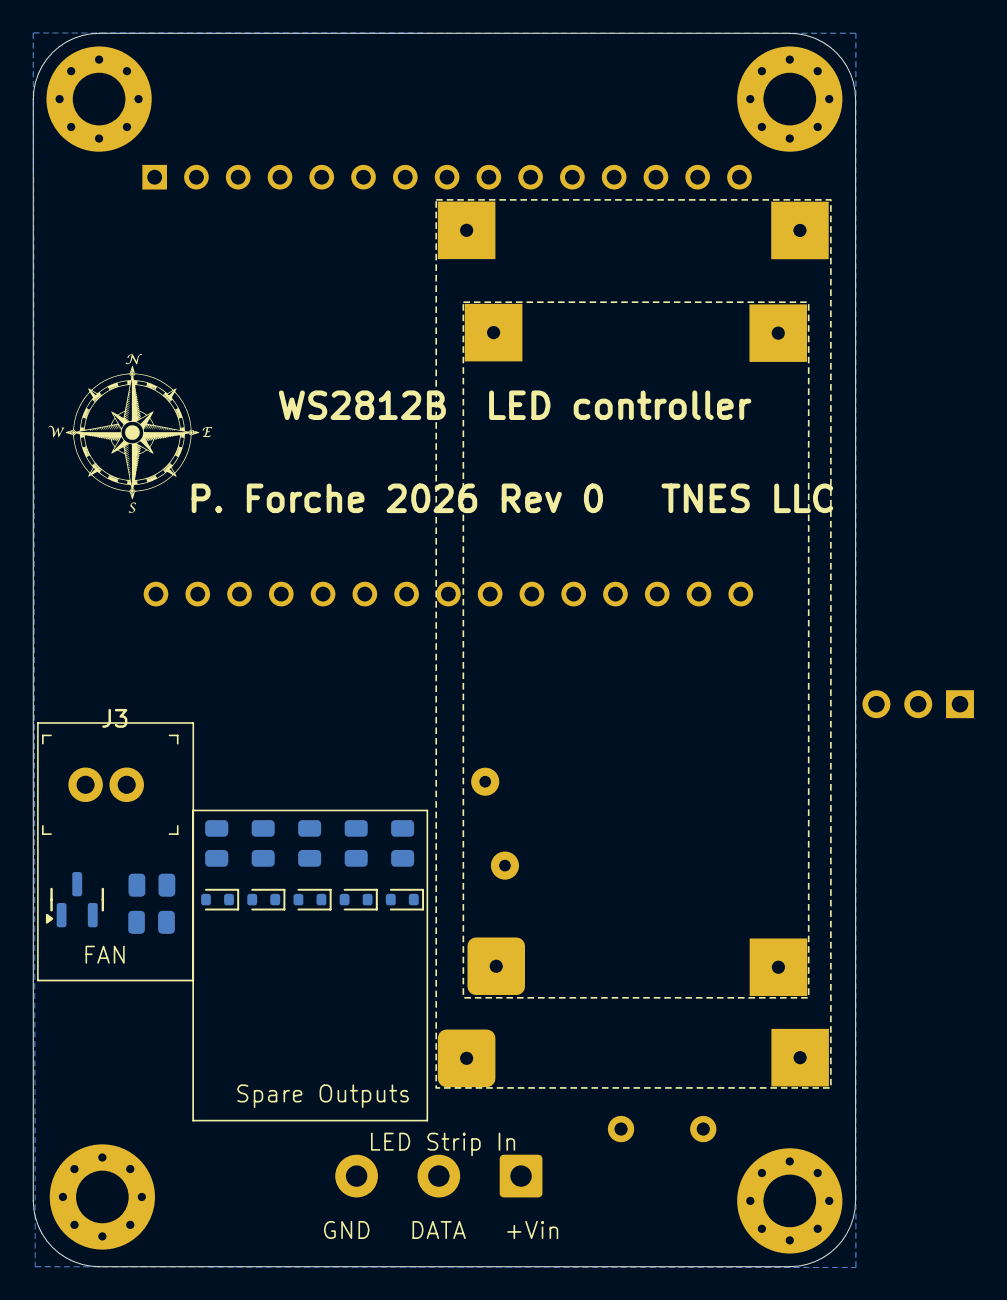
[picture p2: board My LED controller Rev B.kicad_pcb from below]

Board: 2 copper layers, 50.0 x 75.0 mm, 59 parts (16 on the bottom side), 39 nets, no tracks yet.

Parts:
10mm1, 10mm2: 10mm LOGO
BUCK1: Amazon Buck FP
C1, C3, C19: 100nF; C_0805
C2: 100uF; C_1206
C17: 10uF; C_0805
C18: 0.1uF; C_0805
C20: 1000uF; C_Radial_D10.0mm_H12.5mm_P5.00mm
D1, D2, D3: WS2812B; LED-SMD_4P-L1.6-W1.5_XL-1615RGBC-WS2812B
D4: SMAJ26CA; D_SMA
D5: SMAJ5.0CA; D_SMA
D6, D7, D8, D9, D10, D11: ESD5Z5.0T1G; D_SOD-523
D12: 1SMA5927A; D_DO-214AC(SMA)
D13: US1M; D_SMA
F1: PTC RESET FUSE 700mA TH; Fuse_Bourns_MF-RHT100
H1, H2, H3, H4: MHolePad; MountingHole_3.2mm_M3_Pad_Via
J2: Power SEL; PinHeader_2x02_P2.54mm_Vertical_SMD
J3: Fan Control; PinHeader_1x2_P2.5mm_Drill1.1mm
J4: Conn_01x03_Pin; PinHeader_1x03_P2.54mm_Vertical
J5, J6, J7: SPARE_OUT_HDR; PinHeader_2x02_P2.54mm_Vertical_SMD
Q1: BSP322; Q_SOT-23
Q2: AO3400A; Q_SOT-23
R1, R5: 10kΩ; R_0805
R2, R3, R4, R7, R8, R9, R15, R16: 100Ω; R_0805
R6, R10: 100kΩ; R_0805
R12, R13: 4.7k; R_0805
R14: 220Ω; R_0805
SW3: -; SW_TS-1088-AR02016
SW4: +; SW_TS-1088-AR02016
SW5: MODE; SW_TS-1088-AR02016
SW6: POWER; SW_TS-1088-AR02016
U1: ESP32-DevKitM-1; ESP32-C3-DevKitM-1
U4: SN74AHCT125PWR; TSSOP-14_4.4x5mm_P0.65mm
U5: AHT20_C2757850; Humidity sensor
U9: LED_STRIP_CONN; TerminalBlock_Phoenix_MKDS-1,5-3_1x03_P5.00mm_Horizontal

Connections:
3Y: J4.2, R3.1, U4.8 (3Y)
4Y: J5.2, R2.1, U4.11 (4Y)
+3.3V: C2.1, C3.1, R1.1, R12.1, R13.1, R14.1, U1.16 (VDD_3V3)
+5V_CTRL: BUCK1.4 (+Vout), C1.1, C19.2, D1.2 (VDD), D2.2 (VDD), D3.2 (VDD), D5.2, J2.4, J4.3, J5.3, J6.3, U1.15 (Vin), U4.14 (VCC)
GND: BUCK1.1 (-Vin), BUCK1.3 (-Vout), C1.2, C2.2, C3.2, C17.2, C18.2, C19.1, C20.2, D1.3 (GND), D2.3 (GND), D3.3 (GND), D4.1 (A1), D5.1, D6.2 (A), D7.2 (A), D8.2 (A), D9.2 (A), D10.2 (A), D11.2 (A), H1.1, H2.1, H3.1, H4.1, J4.1, J5.1, J6.1, Q2.2 (S), R6.2, R10.2, SW3.2, SW4.2, SW5.2, SW6.2, U1.14 (GND), U1.17 (GND), U4.1 (~1OE), U4.4 (~2OE), U4.7 (GND), U4.10 (~3OE), U4.13 (~4OE), U5.5 (GND), U9.3
GPIO12: R16.2, U1.12 (GPIO12)
GPIO13: J7.2, R8.1, U1.13 (GPIO13)
GPIO14: J7.1, R7.1, U1.11 (GPIO14)
GPIO16: U1.21 (GPIO16), U4.2 (1A)
GPIO17: U1.22 (GPIO17), U4.5 (2A)
GPIO18: U1.24 (GPIO18), U4.12 (4A)
GPIO19: U1.25 (GPIO19), U4.9 (3A)
GPIO23: R9.1, U1.30 (GPIO23)
GPIO34: SW3.1, U1.4 (GPIO34)
GPIO35: SW4.1, U1.5 (GPIO35)
GPIO36: SW5.1, U1.2 (GPIO36)
GPIO39: SW6.1, U1.3 (GPIO39)
LED_STRIP: R15.1, U4.3 (1Y)
unnamed: BUCK1.2 (+Vin), J2.2
unnamed: D1.4 (DIN), R16.1
unnamed: D1.1 (DOUT), D2.4 (DIN)
unnamed: D2.1 (DOUT), D3.4 (DIN)
unnamed: D6.1 (K), R15.2, U9.2
unnamed: D7.1 (K), R4.2
unnamed: D8.1 (K), R3.2
unnamed: D9.1 (K), R2.2
unnamed: D10.1 (K), R8.2
unnamed: D11.1 (K), R7.2
unnamed: D13.2 (A), J3.1, Q2.3 (D)
unnamed: D12.1, Q1.1 (G), R5.2, R6.1
unnamed: Q2.1 (G), R9.2, R10.1
unnamed: R1.2, U1.1 (EN_/_RESET)
unnamed: C17.1, C18.1, R14.2, U5.2 (VDD)
SCL: R12.2, U1.29 (I2C-SCL), U5.3 (SCL)
SDA: R13.2, U1.26 (I2C_SDA), U5.4 (SDA)
VIN_CLAMPED: D4.2 (A2), D13.1 (K), F1.2, J2.1, J2.3, J3.2
VIN_RAW: C20.1, Q1.2 (D), R5.1, U9.1
VIN_REVPROT: D12.2, F1.1, Q1.3 (S)
Y2: J6.2, R4.1, U4.6 (2Y)

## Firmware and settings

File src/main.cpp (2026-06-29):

#include <Arduino.h>
#include <Adafruit_NeoPixel.h>
#include <Adafruit_AHTX0.h>
#include <Wire.h>

#if defined(LED_DATA_PIN)
constexpr uint8_t kLedDataPin = LED_DATA_PIN;
#else
constexpr uint8_t kLedDataPin = 18;
#endif

#if defined(LED_COUNT)
constexpr uint16_t kLedCount = LED_COUNT;
#else
constexpr uint16_t kLedCount = 300;
#endif

#if defined(LED_BRIGHTNESS)
const uint8_t kDefaultBrightness = LED_BRIGHTNESS;
#else
const uint8_t kDefaultBrightness = 32;
#endif

#if defined(ONBOARD_LED_PIN)
const uint8_t kOnboardLedPin = ONBOARD_LED_PIN;
#else
const uint8_t kOnboardLedPin = 19;
#endif

#if defined(ONBOARD_LED_COUNT)
const uint16_t kOnboardLedCount = ONBOARD_LED_COUNT;
#else
const uint16_t kOnboardLedCount = 3;
#endif

#if defined(AHT20_SDA_PIN)
const uint8_t kAht20SdaPin = AHT20_SDA_PIN;
#else
const uint8_t kAht20SdaPin = 21;
#endif

#if defined(AHT20_SCL_PIN)
const uint8_t kAht20SclPin = AHT20_SCL_PIN;
#else
const uint8_t kAht20SclPin = 22;
#endif

#if defined(SWITCH1_PIN)
const uint8_t kSwitchPins[4] = {SWITCH1_PIN, SWITCH2_PIN, SWITCH3_PIN, SWITCH4_PIN};
#else
const uint8_t kSwitchPins[4] = {34, 35, 36, 39};
#endif

#if defined(SWITCH_ACTIVE_LEVEL)
const uint8_t kSwitchActiveLevel = SWITCH_ACTIVE_LEVEL;
#else
const uint8_t kSwitchActiveLevel = LOW;
#endif

#if defined(FIRMWARE_PROFILE_NAME)
const char* kFirmwareProfileName = FIRMWARE_PROFILE_NAME;
#else
const char* kFirmwareProfileName = "unknown";
#endif

const uint16_t kWhiteMilliAmpsPerLed = 60;
const uint32_t kEstimatedFullWhiteMilliAmps = static_cast<uint32_t>(kLedCount) * kWhiteMilliAmpsPerLed;
const uint16_t kSteadyCurrentLimitMa = 12000;
const uint16_t kHardMaxCurrentLimitMa = 15000;

Adafruit_NeoPixel strip(kLedCount, kLedDataPin, NEO_GRB + NEO_KHZ800);
Adafruit_NeoPixel onboardStrip(kOnboardLedCount, kOnboardLedPin, NEO_GRB + NEO_KHZ800);
Adafruit_AHTX0 aht20;

enum class LedMode : uint8_t {
  Rainbow,
  Demo,
  Solid,
  Off
};

uint8_t userBrightness = kDefaultBrightness;
uint8_t brightnessCap = 255;
uint16_t hueOffset = 0;
uint32_t lastFrameMs = 0;
LedMode mode = LedMode::Rainbow;
uint32_t solidColor = 0;
uint32_t demoStartMs = 0;
uint16_t demoStep = 0;
bool aht20Ready = false;
uint8_t switchStableState[4] = {0, 0, 0, 0};
uint8_t switchLastSample[4] = {0, 0, 0, 0};
uint32_t switchLastDebounceMs[4] = {0, 0, 0, 0};
constexpr uint32_t kSwitchDebounceMs = 30;

static uint8_t effectiveBrightness() {
  return min(userBrightness, brightnessCap);
}

static uint8_t currentLimitToBrightnessCap(uint16_t currentLimitMa) {
  if (currentLimitMa >= kEstimatedFullWhiteMilliAmps) {
    return 255;
  }

  const uint32_t cappedBrightness = (static_cast<uint32_t>(currentLimitMa) * 255U + kEstimatedFullWhiteMilliAmps - 1U) / kEstimatedFullWhiteMilliAmps;
  return static_cast<uint8_t>(constrain(cappedBrightness, 1UL, 255UL));
}

static void applyBrightness() {
  strip.setBrightness(effectiveBrightness());
  onboardStrip.setBrightness(effectiveBrightness());
}

static void initBoardInputs() {
  const uint32_t now = millis();
  for (uint8_t i = 0; i < 4; ++i) {
    pinMode(kSwitchPins[i], INPUT);
    const uint8_t sample = static_cast<uint8_t>(digitalRead(kSwitchPins[i]));
    switchStableState[i] = sample;
    switchLastSample[i] = sample;
    switchLastDebounceMs[i] = now;
  }
}

static void pollSwitchPresses(uint32_t nowMs) {
  for (uint8_t i = 0; i < 4; ++i) {
    const uint8_t sample = static_cast<uint8_t>(digitalRead(kSwitchPins[i]));

    if (sample != switchLastSample[i]) {
      switchLastSample[i] = sample;
      switchLastDebounceMs[i] = nowMs;
    }

    if ((nowMs - switchLastDebounceMs[i] >= kSwitchDebounceMs) && (sample != switchStableState[i])) {
      switchStableState[i] = sample;
      if (sample == kSwitchActiveLevel) {
        Serial.printf("Switch S%u pressed\n", i + 1);
      }
    }
  }
}

static void initAht20() {
  Wire.begin(kAht20SdaPin, kAht20SclPin);
  aht20Ready = aht20.begin(&Wire);
}

static void printSwitchStates() {
  Serial.printf("Switches (raw): S1=%d S2=%d S3=%d S4=%d\n",
                digitalRead(kSwitchPins[0]),
                digitalRead(kSwitchPins[1]),
                digitalRead(kSwitchPins[2]),
                digitalRead(kSwitchPins[3]));
}

static void printAht20Reading() {
  if (!aht20Ready) {
    initAht20();
  }

  if (!aht20Ready) {
    Serial.printf("AHT20 not detected on I2C SDA=%u SCL=%u\n", kAht20SdaPin, kAht20SclPin);
    return;
  }

  sensors_event_t humidity;
  sensors_event_t temp;
  aht20.getEvent(&humidity, &temp);
  Serial.printf("AHT20: temp=%.2f C humidity=%.2f %%RH\n", temp.temperature, humidity.relative_humidity);
}

static void scanI2cBus() {
  Wire.begin(kAht20SdaPin, kAht20SclPin);
  Serial.printf("Scanning I2C bus on SDA=%u SCL=%u...\n", kAht20SdaPin, kAht20SclPin);

  uint8_t foundCount = 0;
  for (uint8_t address = 1; address < 127; ++address) {
    Wire.beginTransmission(address);
    const uint8_t error = Wire.endTransmission();
    if (error == 0) {
      Serial.printf("I2C device found at 0x%02X\n", address);
      ++foundCount;
    }
  }

  if (foundCount == 0) {
    Serial.println("No I2C devices found");
  } else {
    Serial.printf("I2C scan complete: %u device(s) found\n", foundCount);
  }
}

static void pulseProbePin() {
  pinMode(kLedDataPin, OUTPUT);
  digitalWrite(kLedDataPin, LOW);
  delay(100);
  for (uint8_t i = 0; i < 8; ++i) {
    digitalWrite(kLedDataPin, HIGH);
    delay(80);
    digitalWrite(kLedDataPin, LOW);
    delay(80);
  }
}

static uint32_t wheel(uint8_t wheelPos) {
  wheelPos = 255 - wheelPos;
  if (wheelPos < 85) {
    return strip.Color(255 - wheelPos * 3, 0, wheelPos * 3);
  }
  if (wheelPos < 170) {
    wheelPos -= 85;
    return strip.Color(0, wheelPos * 3, 255 - wheelPos * 3);
  }
  wheelPos -= 170;
  return strip.Color(wheelPos * 3, 255 - wheelPos * 3, 0);
}

static void clearStrip() {
  strip.clear();
  strip.show();
  onboardStrip.clear();
  onboardStrip.show();
}

static void showSolid(uint32_t color) {
  for (uint16_t i = 0; i < kLedCount; ++i) {
    strip.setPixelColor(i, color);
  }
  strip.show();
  for (uint16_t i = 0; i < kOnboardLedCount; ++i) {
    onboardStrip.setPixelColor(i, color);
  }
  onboardStrip.show();
}

static void renderRainbowStep() {
  for (uint16_t i = 0; i < kLedCount; ++i) {
    const uint8_t colorIndex = static_cast<uint8_t>((i * 256U / kLedCount + hueOffset) & 0xFFU);
    strip.setPixelColor(i, wheel(colorIndex));
  }
  strip.show();
  for (uint16_t i = 0; i < kOnboardLedCount; ++i) {
    const uint8_t colorIndex = static_cast<uint8_t>((i * 256U / kOnboardLedCount + hueOffset) & 0xFFU);
    onboardStrip.setPixelColor(i, wheel(colorIndex));
  }
  onboardStrip.show();
  hueOffset++;
}

static void renderDemoStep(uint32_t nowMs) {
  constexpr uint32_t kPhaseDurationMs = 7000;
  const uint32_t elapsedMs = nowMs - demoStartMs;
  const uint8_t phase = static_cast<uint8_t>((elapsedMs / kPhaseDurationMs) % 4U);
  const uint16_t localStep = static_cast<uint16_t>(elapsedMs / 18U);

  if (phase == 0) {
    for (uint16_t i = 0; i < kLedCount; ++i) {
      const uint8_t colorIndex = static_cast<uint8_t>((i * 512U / kLedCount + localStep * 2U) & 0xFFU);
      strip.setPixelColor(i, wheel(colorIndex));
    }
    strip.show();
    for (uint16_t i = 0; i < kOnboardLedCount; ++i) {
      const uint8_t colorIndex = static_cast<uint8_t>((i * 512U / kOnboardLedCount + localStep * 2U) & 0xFFU);
      onboardStrip.setPixelColor(i, wheel(colorIndex));
    }
    onboardStrip.show();
    return;
  }

  if (phase == 1) {
    const uint8_t chaseOffset = static_cast<uint8_t>(localStep % 9U);
    const uint32_t palette[3] = {
      strip.Color(255, 10, 0),
      strip.Color(0, 180, 255),
      strip.Color(40, 255, 40)
    };

    for (uint16_t i = 0; i < kLedCount; ++i) {
      if (((i + chaseOffset) % 9U) < 3U) {
        strip.setPixelColor(i, palette[(i / 3U + localStep) % 3U]);
      } else {
        strip.setPixelColor(i, 0);
      }
    }
    strip.show();
    for (uint16_t i = 0; i < kOnboardLedCount; ++i) {
      if (((i + chaseOffset) % 9U) < 3U) {
        onboardStrip.setPixelColor(i, palette[(i / 3U + localStep) % 3U]);
      } else {
        onboardStrip.setPixelColor(i, 0);
      }
    }
    onboardStrip.show();
    return;
  }

  if (phase == 2) {
    const uint16_t cometHead = static_cast<uint16_t>((localStep * 3U) % kLedCount);
    for (uint16_t i = 0; i < kLedCount; ++i) {
      const uint16_t distance = static_cast<uint16_t>((kLedCount + cometHead - i) % kLedCount);
      if (distance < 24U) {
        const uint8_t fade = static_cast<uint8_t>(255U - distance * 10U);
        strip.setPixelColor(i, strip.Color(fade, fade / 6U, fade));
      } else {
        strip.setPixelColor(i, 0);
      }
    }
    strip.show();
    const uint16_t onboardCometHead = static_cast<uint16_t>((localStep * 3U) % kOnboardLedCount);
    for (uint16_t i = 0; i < kOnboardLedCount; ++i) {
      const uint16_t distance = static_cast<uint16_t>((kOnboardLedCount + onboardCometHead - i) % kOnboardLedCount);
      if (distance < 24U) {
        const uint8_t fade = static_cast<uint8_t>(255U - distance * 10U);
        onboardStrip.setPixelColor(i, onboardStrip.Color(fade, fade / 6U, fade));
      } else {
        onboardStrip.setPixelColor(i, 0);
      }
    }
    onboardStrip.show();
    return;
  }

  const bool flashOn = ((localStep / 3U) % 2U) == 0U;
  if (flashOn) {
    const uint32_t pulseColor = wheel(static_cast<uint8_t>((localStep * 5U) & 0xFFU));
    for (uint16_t i = 0; i < kLedCount; ++i) {
      strip.setPixelColor(i, pulseColor);
    }
    for (uint16_t i = 0; i < kOnboardLedCount; ++i) {
      onboardStrip.setPixelColor(i, pulseColor);
    }
  } else {
    for (uint16_t i = 0; i < kLedCount; ++i) {
      strip.setPixelColor(i, 0);
    }
    for (uint16_t i = 0; i < kOnboardLedCount; ++i) {
      onboardStrip.setPixelColor(i, 0);
    }
  }
  strip.show();
  onboardStrip.show();
}

static void runStartupDiagnostic() {
  const uint32_t colors[] = {
    strip.Color(255, 0, 0),
    strip.Color(0, 255, 0),
    strip.Color(0, 0, 255),
    strip.Color(255, 255, 255)
  };

  for (uint8_t c = 0; c < 4; ++c) {
    showSolid(colors[c]);
    delay(350);
    clearStrip();
    delay(120);
  }
  Serial.println("Startup diagnostic: on-board 3 LEDs + external strip tested RGBW");
}

static void handleSerial() {
  if (!Serial.available()) {
    return;
  }

  String cmd = Serial.readStringUntil('\n');
  cmd.trim();
  cmd.toLowerCase();

  if (cmd == "off") {
    mode = LedMode::Off;
    clearStrip();
    Serial.println("LEDs off");
    return;
  }

  if (cmd == "on") {
    mode = LedMode::Rainbow;
    applyBrightness();
    Serial.println("LED animation on (rainbow)");
    return;
  }

  if (cmd == "demo") {
    mode = LedMode::Demo;
    demoStartMs = millis();
    demoStep = 0;
    applyBrightness();
    Serial.println("Mode: demo");
    return;
  }

  if (cmd == "rainbow") {
    mode = LedMode::Rainbow;
    Serial.println("Mode: rainbow");
    return;
  }

  if (cmd == "white") {
    mode = LedMode::Solid;
    solidColor = strip.Color(255, 255, 255);
    showSolid(solidColor);
    Serial.println("Mode: solid white");
    return;
  }

  if (cmd == "red") {
    mode = LedMode::Solid;
    solidColor = strip.Color(255, 0, 0);
    showSolid(solidColor);
    Serial.println("Mode: solid red");
    return;
  }

  if (cmd == "green") {
    mode = LedMode::Solid;
    solidColor = strip.Color(0, 255, 0);
    showSolid(solidColor);
    Serial.println("Mode: solid green");
    return;
  }

  if (cmd == "blue") {
    mode = LedMode::Solid;
    solidColor = strip.Color(0, 0, 255);
    showSolid(solidColor);
    Serial.println("Mode: solid blue");
    return;
  }

  if (cmd == "probe") {
    Serial.println("Running raw GPIO probe pulse on data pin");
    pulseProbePin();
    strip.begin();
    applyBrightness();
    Serial.println("Probe done");
    return;
  }

  if (cmd == "aht20" || cmd == "sensor") {
    printAht20Reading();
    return;
  }

  if (cmd == "i2cscan" || cmd == "scan") {
    scanI2cBus();
    return;
  }

  if (cmd == "switches" || cmd == "switch" || cmd == "inputs") {
    printSwitchStates();
    return;
  }

  if (cmd == "boardcheck" || cmd == "diag") {
    printAht20Reading();
    printSwitchStates();
    return;
  }

  if (cmd == "test12" || cmd == "12a") {
    mode = LedMode::Solid;
    userBrightness = 255;
    brightnessCap = currentLimitToBrightnessCap(12000);
    solidColor = strip.Color(255, 255, 255);
    applyBrightness();
    showSolid(solidColor);
    Serial.printf("12A test active: brightness cap %u, effective brightness %u\n", brightnessCap, effectiveBrightness());
    return;
  }

  if (cmd == "nolimit") {
    brightnessCap = currentLimitToBrightnessCap(kHardMaxCurrentLimitMa);
    applyBrightness();
    if (mode == LedMode::Solid) {
      showSolid(solidColor);
    }
    Serial.printf("Current limit set to hard max %u mA\n", kHardMaxCurrentLimitMa);
    return;
  }

  if (cmd.startsWith("limit")) {
    int value = cmd.substring(5).toInt();
    value = constrain(value, 0, static_cast<int>(kHardMaxCurrentLimitMa));
    brightnessCap = currentLimitToBrightnessCap(static_cast<uint16_t>(value));
    applyBrightness();
    if (mode == LedMode::Solid) {
      showSolid(solidColor);
    }
    Serial.printf("Current limit set to %d mA; brightness cap %u; effective brightness %u\n", value, brightnessCap, effectiveBrightness());
    return;
  }

  if (cmd.startsWith("b")) {
    int value = cmd.substring(1).toInt();
    value = constrain(value, 0, 255);
    userBrightness = static_cast<uint8_t>(value);
    applyBrightness();
    if (mode == LedMode::Solid) {
      showSolid(solidColor);
    }
    Serial.printf("Brightness set to %u (effective %u)\n", userBrightness, effectiveBrightness());
    return;
  }

  Serial.println("Commands: on|demo|rainbow|off|white|red|green|blue|probe|aht20|sensor|i2cscan|scan|switches|boardcheck|test12|12a|limit<ma>|nolimit|b<0-255>");
}

void setup() {
  Serial.begin(115200);
  delay(300);

  pulseProbePin();
  initBoardInputs();
  initAht20();
  strip.begin();
  onboardStrip.begin();
  brightnessCap = currentLimitToBrightnessCap(kSteadyCurrentLimitMa);
  applyBrightness();
  clearStrip();
  runStartupDiagnostic();

  Serial.println();
  Serial.println("My LED Controller ready");
  Serial.printf("Firmware profile: %s\n", kFirmwareProfileName);
  Serial.printf("External strip: GPIO%u, LED count: %u\n", kLedDataPin, kLedCount);
  Serial.printf("On-board LEDs: GPIO%u, LED count: %u\n", kOnboardLedPin, kOnboardLedCount);
  Serial.printf("AHT20 I2C: SDA=%u SCL=%u (%s)\n", kAht20SdaPin, kAht20SclPin, aht20Ready ? "ready" : "not detected");
  Serial.printf("Switch inputs: GPIO%u GPIO%u GPIO%u GPIO%u\n", kSwitchPins[0], kSwitchPins[1], kSwitchPins[2], kSwitchPins[3]);
  Serial.printf("Switch logging: active level %u, debounce %lu ms\n", kSwitchActiveLevel, static_cast<unsigned long>(kSwitchDebounceMs));
  Serial.printf("Brightness: %u, steady limit: %u mA, max limit: %u mA\n", userBrightness, kSteadyCurrentLimitMa, kHardMaxCurrentLimitMa);
  Serial.println("Commands: on|demo|rainbow|off|white|red|green|blue|probe|aht20|sensor|i2cscan|scan|switches|boardcheck|test12|12a|limit<ma>|nolimit|b<0-255>");
}

void loop() {
  const uint32_t now = millis();
  pollSwitchPresses(now);
  handleSerial();

  if (mode == LedMode::Rainbow && now - lastFrameMs >= 20) {
    lastFrameMs = now;
    renderRainbowStep();
  }

  if (mode == LedMode::Demo && now - lastFrameMs >= 18) {
    lastFrameMs = now;
    demoStep++;
    renderDemoStep(now);
  }

  if (mode == LedMode::Solid) {
    delay(10);
  }
}

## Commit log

2026-06-22 Swap Q1 gate bias resistors: R5 100k (to VIN_RAW), R6 10k (to GND) for better PMOS turn-on at 5V input
    [My LED controller.kicad_pcb, My LED controller.kicad_sch]
2026-06-22 Add handoff document for board connection & validation phase
2026-06-24 Implement pin remap docs and add spare AHCT125 SMT breakout header
    [My LED controller.kicad_pcb, My LED controller.kicad_sch]
2026-06-24 Schematic: mirror WS2812 symbols and adjust annotation placement
    [My LED controller.kicad_sch]
2026-06-29 Add Rev B design baseline and prefab mic closeout artifacts
    [My LED controller Rev B.kicad_pcb, My LED controller Rev B.kicad_sch]
